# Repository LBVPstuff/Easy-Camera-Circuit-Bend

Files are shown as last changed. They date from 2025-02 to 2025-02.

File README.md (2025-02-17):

# Easy-Camera-Circuit-Bend

An easy way to circuit bend a toy camera with a CMOS chip to take glitchy pictures, with only basic skills needed in soldering.

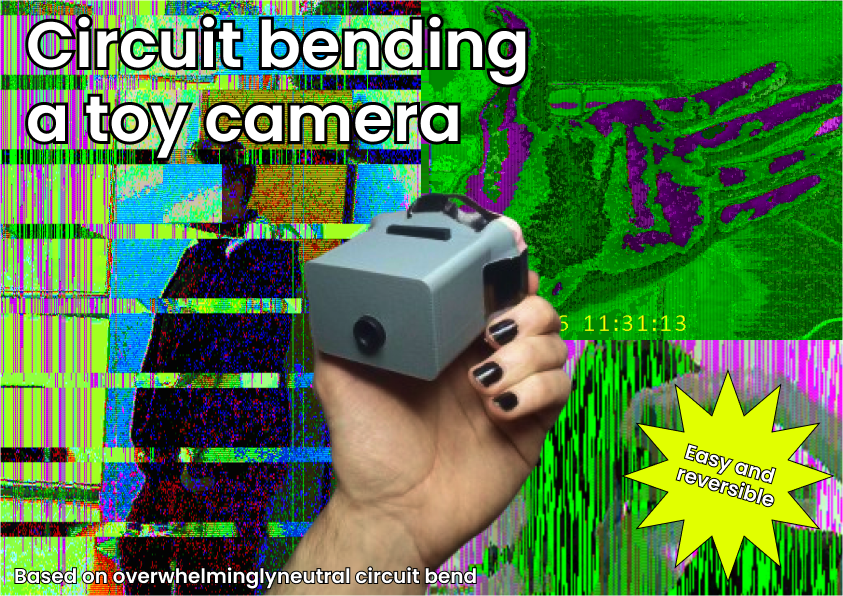
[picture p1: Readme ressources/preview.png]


:warning: **Big disclaimer here:** I did not invented this hack, I discovered it with [this cool video](https://www.youtube.com/watch?v=hnv6Nud2QAo) by [overwhelminglyneutral (cool person)](https://www.youtube.com/@oneutral101) and I wanted to add more to it while making it more practical to use, by being able to switch between different effects.

The modifications we will be doing to the camera are reversible and not directly soldered to the board, making it easy to swap if you need to get back to a normal toy camera.

## *What is circuit bending*

Wikipedia says circuit bending is the creative customization of the circuits within electronic devices such as children's toys and digital synthesizer to create new musical or visual instruments and sound generators. Circuit bending is manipulating a circuit to get an output that was not intended by the manufacturer.
It is a really interesting and creative topic, but sometimes I find that it can get quite esoteric and difficult to understand, especially if you have no knowledge in electronics to begin with. I wanted this project to be achievable by people with very little skills with soldering (like me) so everyone can try this little hack and take cool pictures. I will try my best to include a lot of details.

## *How this circuit bend works ?*

Within this camera, there is a camera module, sending information to the motherboard inside the main body. This camera basically tells what it sees throught electric signals throught 24 tiny cables and the motherboard is processing this signal to display it on the screen, save it on the SD card, add filters etc.

What we want to do is mix thoses signals together by shorting some pins together and mess with the signals being sent to the motherboard.

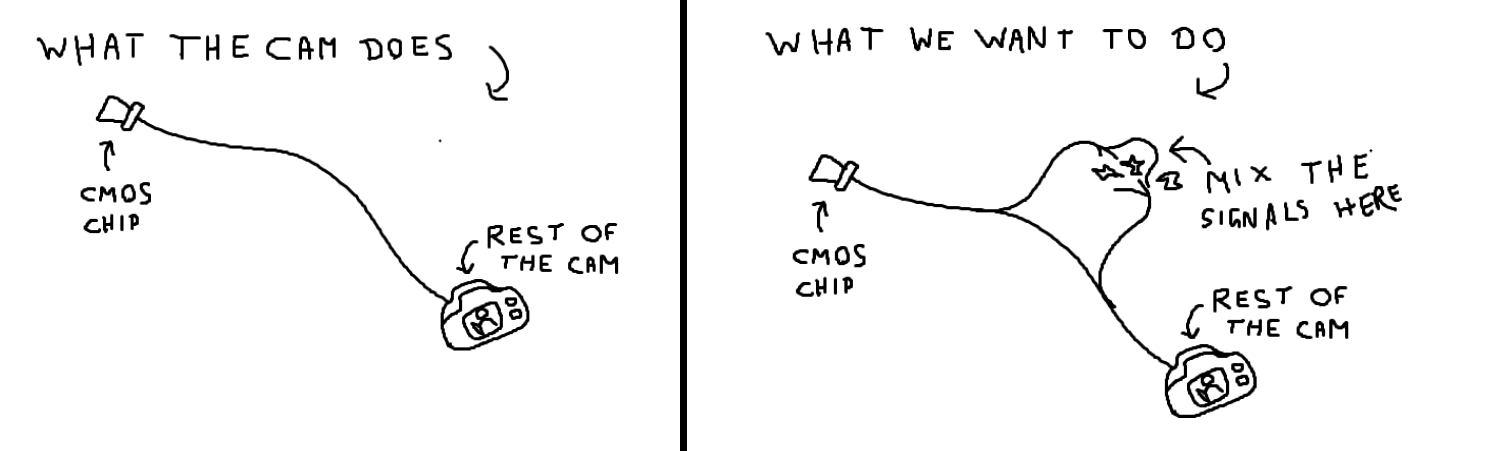
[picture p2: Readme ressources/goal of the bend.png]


To achieve this, you are supposed to solder tiny enameled copper wire to the 0.5mm ribbon cable connector pins on the main board, but it was way too difficult for me so I found an other way using adaptor cards and a spare ribbon cable. The result looks like this without a case to hold everything together :

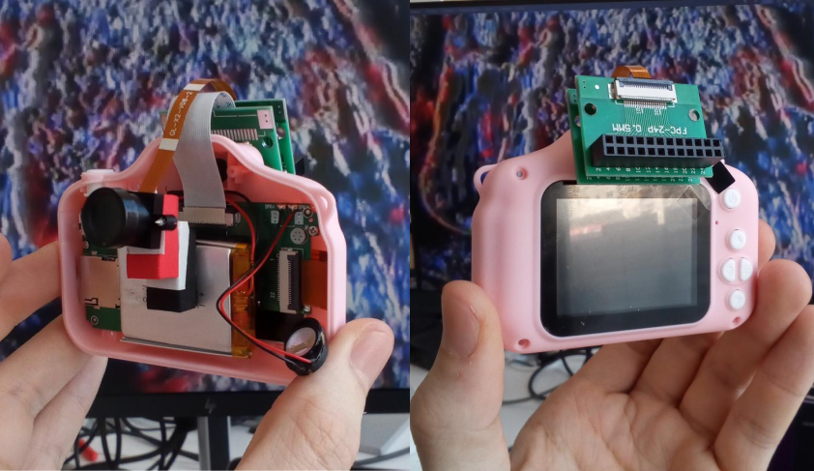
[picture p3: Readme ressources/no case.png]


## *Tools and materials you will need*

### [The toy camera](https://www.amazon.fr/Faburo-Appareil-Num%C3%A9rique-Mpixels-Gar%C3%A7ons/dp/B07W45FTG8)
The Toy camera I used was [this Faburo Toy Camera](https://www.amazon.fr/Faburo-Appareil-Num%C3%A9rique-Mpixels-Gar%C3%A7ons/dp/B07W45FTG8). It is available on amazon and is pretty cheap, around 16 euros. There are also the same cameras available on aliexpress for a little cheaper if you are willing to wait a little bit more. Also, it is a good idea to check on the seconde hand market first, I found several there.

This circuit bend probably also work on many other cheap toy camera such as theses ones:

_______________________________________________________________________________

### Two [24 pin Ribbon cable to pins converter boards](https://fr.aliexpress.com/item/1005005485116729.html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,scm-url:1007.40050.354490.0,pvid:dd1d1b7d-951f-4a07-9ccf-86fbf27bccbe,tpp_buckets:668%232846%238113%231998&pdp_npi=4%40dis%21EUR%212.00%210.99%21%21%2114.70%217.27%21%40211b61a417367906687343405e3798%2112000033269437110%21rec%21FR%21%21ABX&utparam-url=scene%3ApcDetailTopMoreOtherSeller%7Cquery_from%3A)
I ordered them from aliexpress because it was the easiest way for me to souce these parts. The most important thing to know is that we need a **24pin adaptor with 0.5mm of paths thickness**. So make sure to tick the same boxes like in the picture when you order. **We will need 2 of these.**

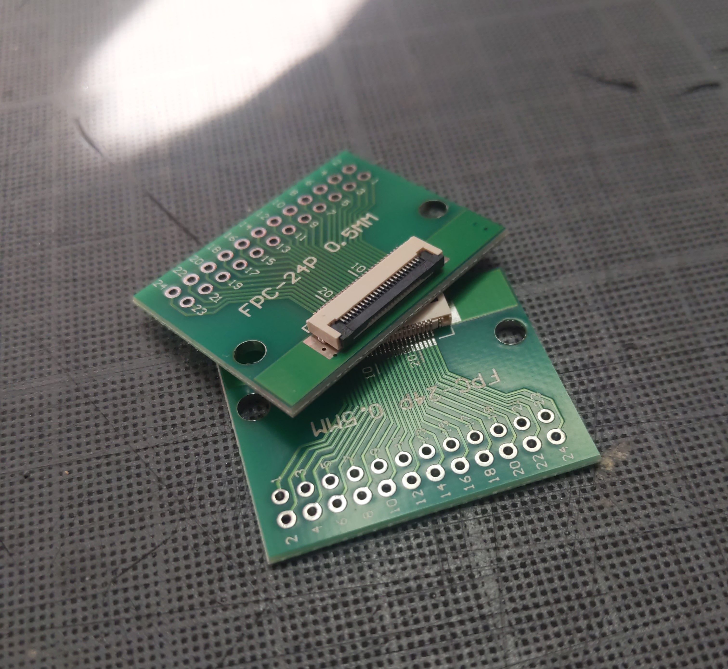
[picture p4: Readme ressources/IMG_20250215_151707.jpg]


_______________________________________________________________________________

### Two rows 24 pins headers

I used a longer one that I trimmed to size, but you can find 24pins ones if you want. This will be used to connect the two adapter boards together. Alternatively, you can connect the big pins from the adapter boards directly to other stuff you want to use to short the pins, but I find this much easier and will be handy later.

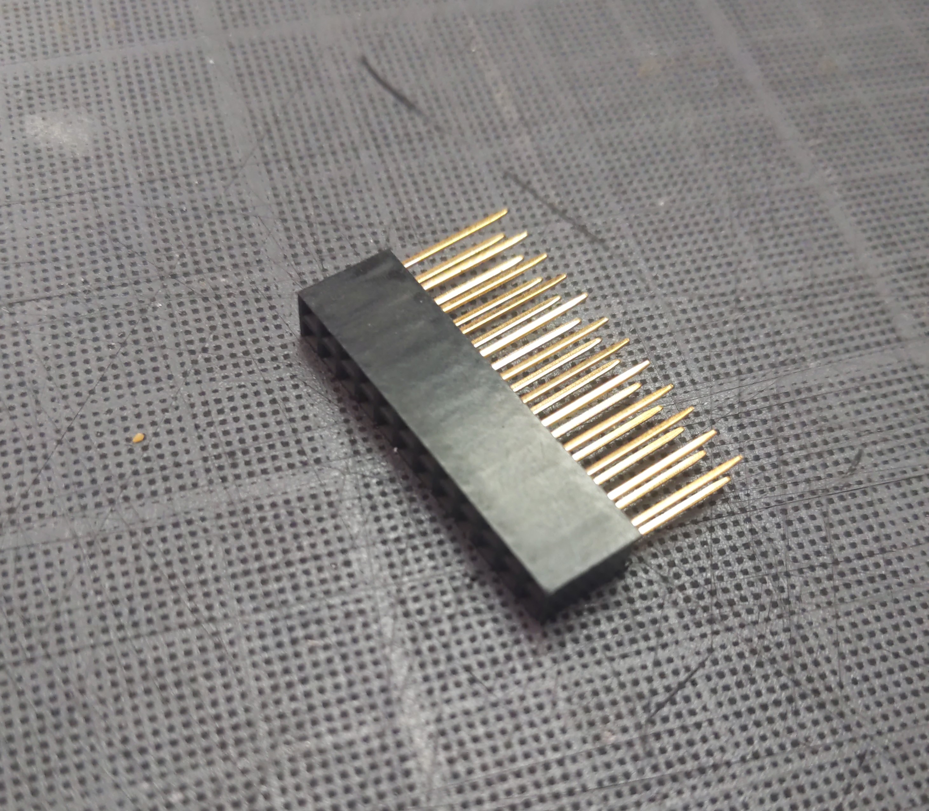
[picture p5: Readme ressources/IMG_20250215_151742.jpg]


_______________________________________________________________________________

### Longer [24pin ribbon cable](https://fr.aliexpress.com/item/1005005982573926.html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)
In order to connect the adaptor boards back to the main board of the camera, we will need another ribbon cable like this one :
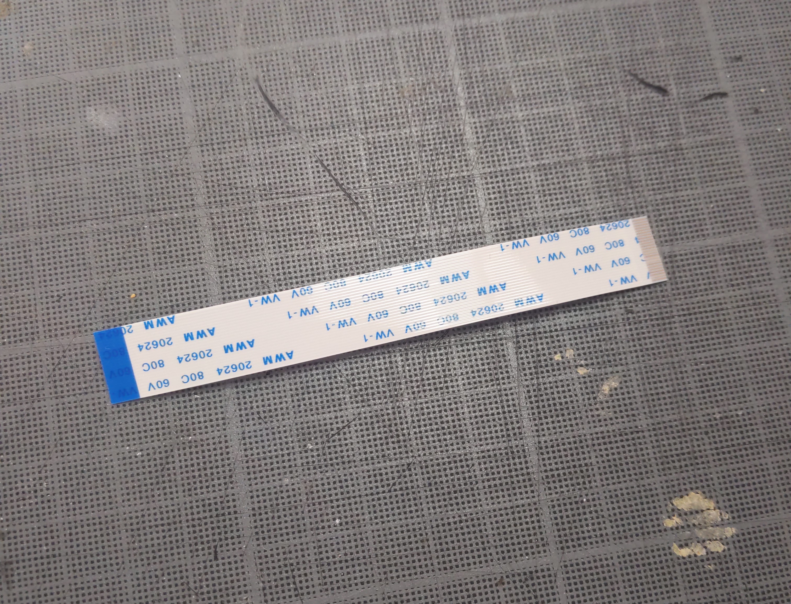
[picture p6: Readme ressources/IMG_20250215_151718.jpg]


:warning: Make sure it is a **24pin ribbon cable with a thickness of 0.5mm**. I chose a length of 10cm, since it will more than enough for my case.

_______________________________________________________________________________

### Jumper wire
Or any wire that fits into our 24 pins header just to trigger the bends once we are finished.

_______________________________________________________________________________

### A soldering Iron

Any soldering iron will do, we are not going to do complex stuff with it, just make sure its tip is clean. If you don't know of to solder, i found [this video that cover all the steps we will need](https://www.youtube.com/watch?v=Qps9woUGkvI).

_______________________________________________________________________________

### Solder
Try using lead free solder, but again any solder will do the trick here.

_______________________________________________________________________________

### A small phillips screwdriver
We will be using it to disassemble the camera

## *Step by step guide*

I made a video tutorial on Youtube that covers all the steps to assemble the module, i find it easier to understand this way:

(https://www.youtube.com/watch?v=pKovYRPuqpo)

Also you can find the complete pinout of the bends I found with [this link](https://docs.google.com/spreadsheets/d/120eRuoZbcSEhcIwTfrmM8TAaZlizbV74gkXWp9CGXoM/edit?usp=sharing), or in PDF format in the folder Pinout] of this repo. As mentionned in the video, **I strongly advise you to test out the bends on your particular camera**, since those are very cheap and vary a lot on one another, even with the same models.

After completing the module and plugging it into the camera, you will need a way to hold everything together nicely. To do so, I 3D modeled a new case for the camera, with more space to fit everything into it. If you have access to a 3D printer, you can print this with the flat side facing down with no support.

Then you just have to screw the camera module inside it, stick the connector pins throught the hole and plug the ribbon cable back into the camera. The current case holds together with duct tape but maybe later I will 3D model a new cas uses the screws used the hold the camera together originally.

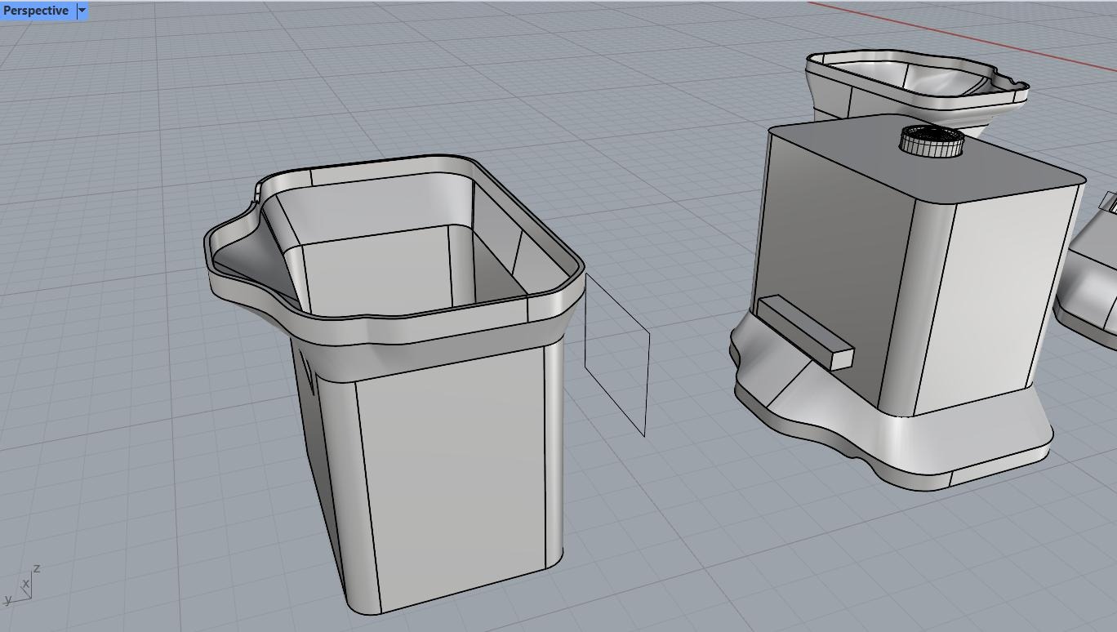
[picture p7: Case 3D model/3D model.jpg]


:warning: **Make sure to test if the module works before putting it into its new case or it will be annoying to take it appart**

The 3D model can be found in this repo into the **Case 3D model folder**.

## *Future of this project*

I plan on doing "presets" for this camera. Using the exposed connector, i can plug a specific short that creates a glitch effect I like and have multiple of those presets modules into my pocket and switch between them idk.

Also I would like to do some "shields" that plung onto the connectors and able manual control with switch and potentiometers over the more interestings bends such as the pin 1 6 and 20. I have drawn some ideas and I could be a cool project to learn about PCB making.

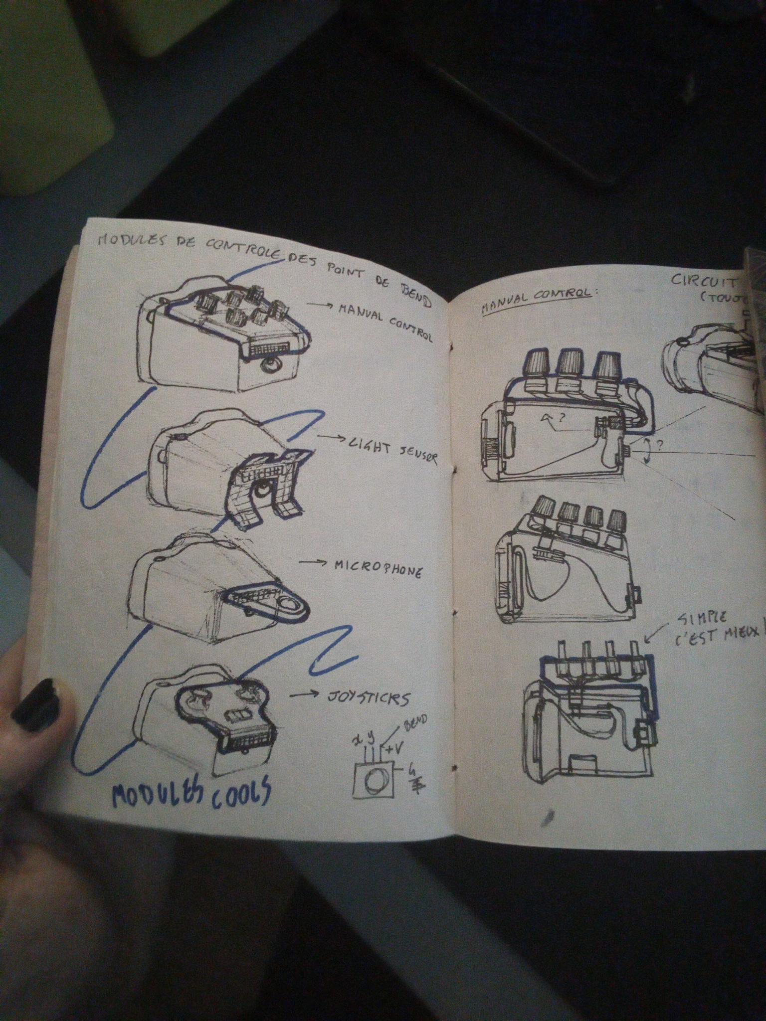
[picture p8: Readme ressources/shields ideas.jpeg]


## *Here are some picture I took with it*

The timestamp can be removed in the parameters of the camera, and the image quality (mostly the size of the image on your SD card) can be changed as well. I am using 2 jumper cables for most of my pictures.

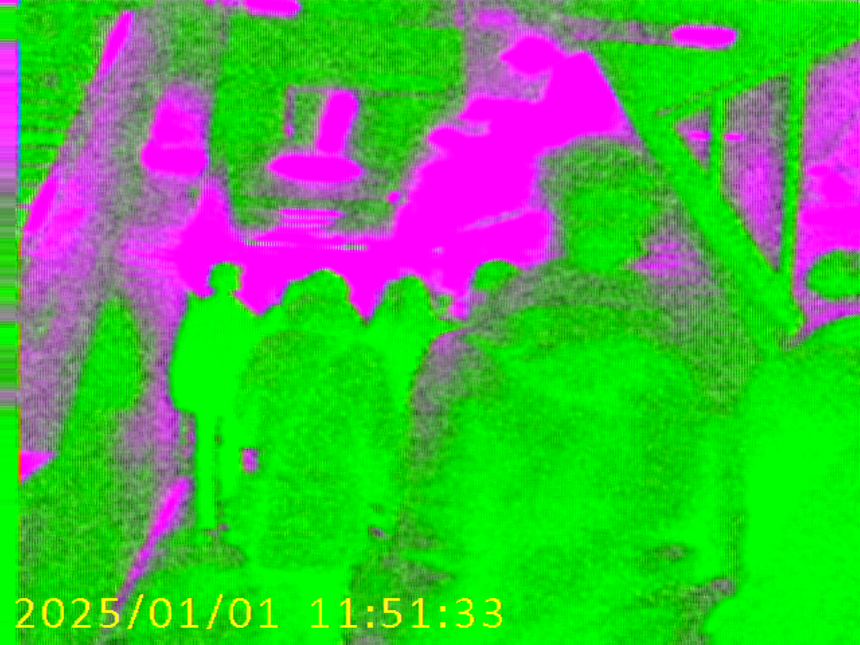
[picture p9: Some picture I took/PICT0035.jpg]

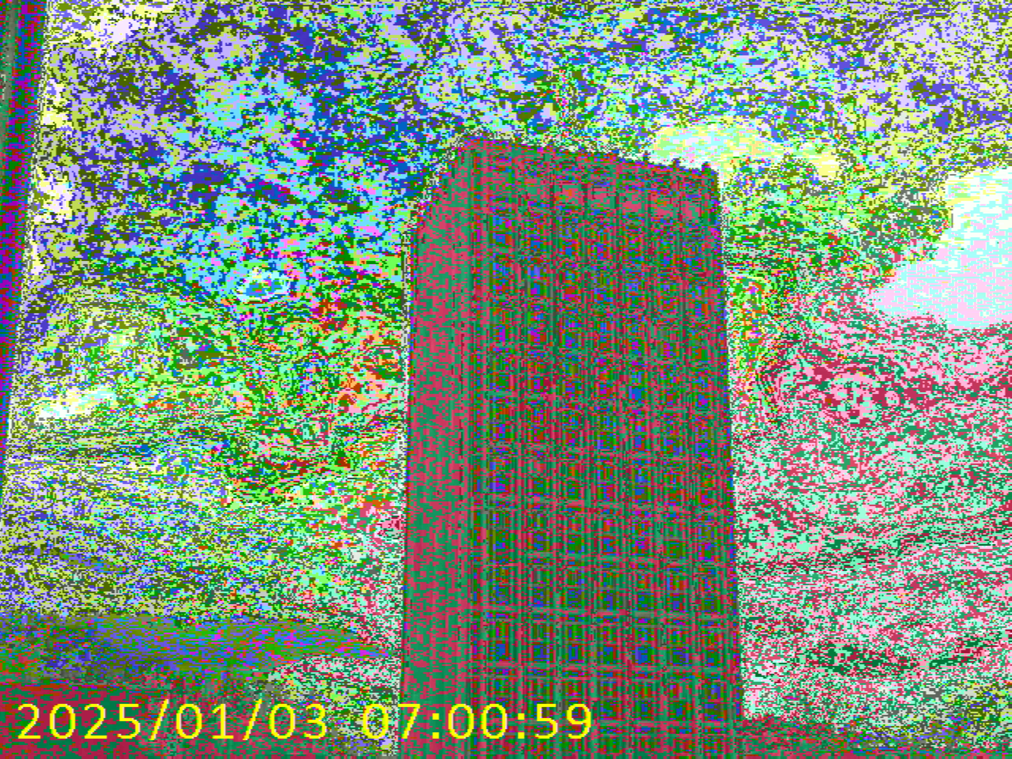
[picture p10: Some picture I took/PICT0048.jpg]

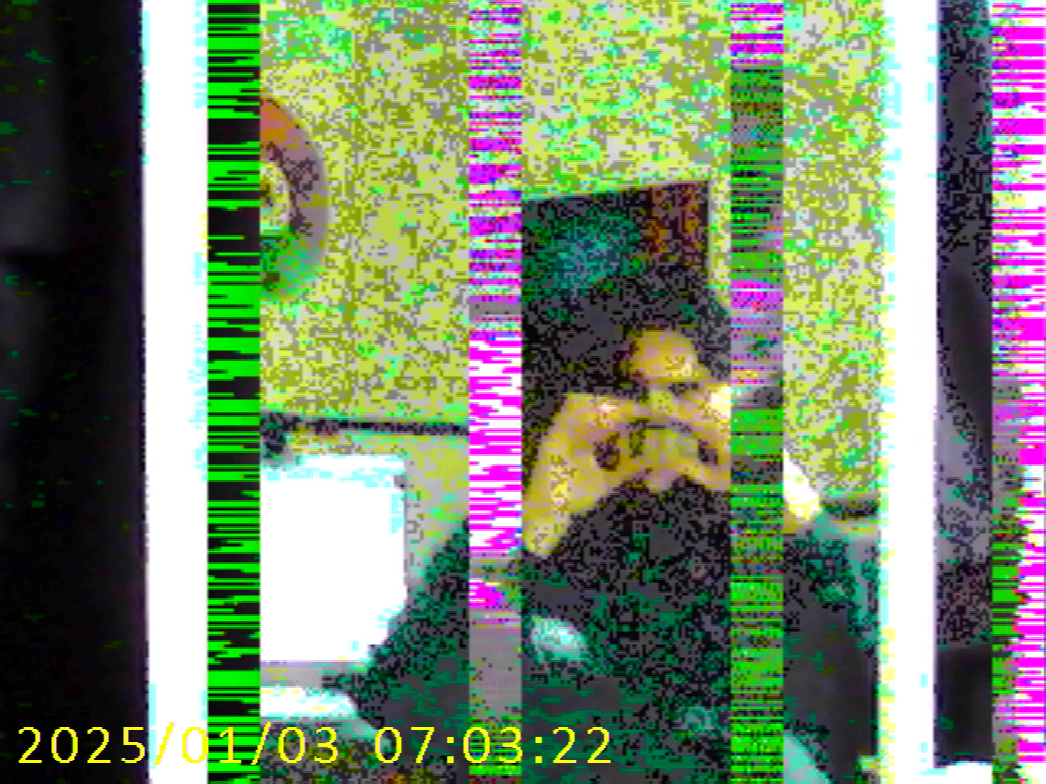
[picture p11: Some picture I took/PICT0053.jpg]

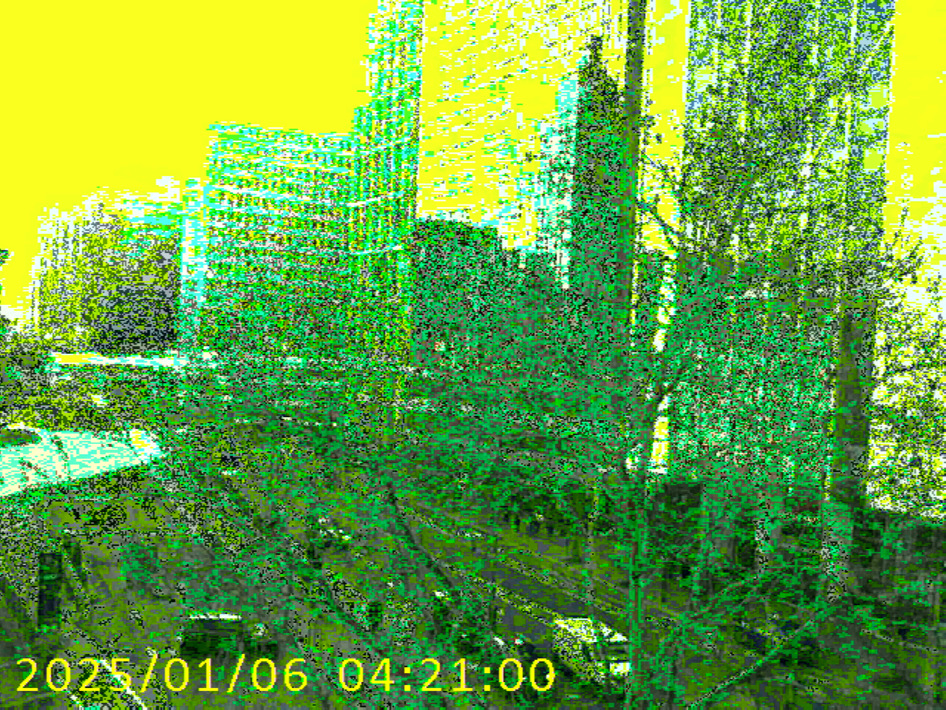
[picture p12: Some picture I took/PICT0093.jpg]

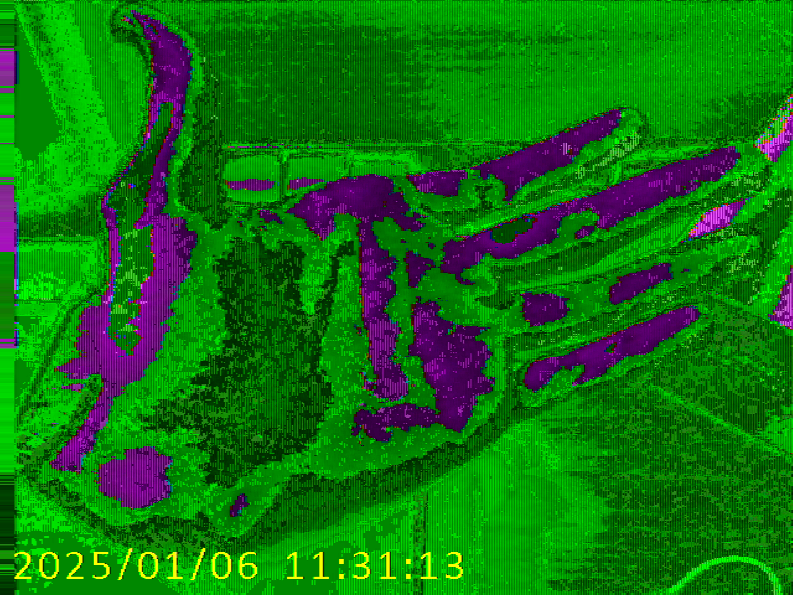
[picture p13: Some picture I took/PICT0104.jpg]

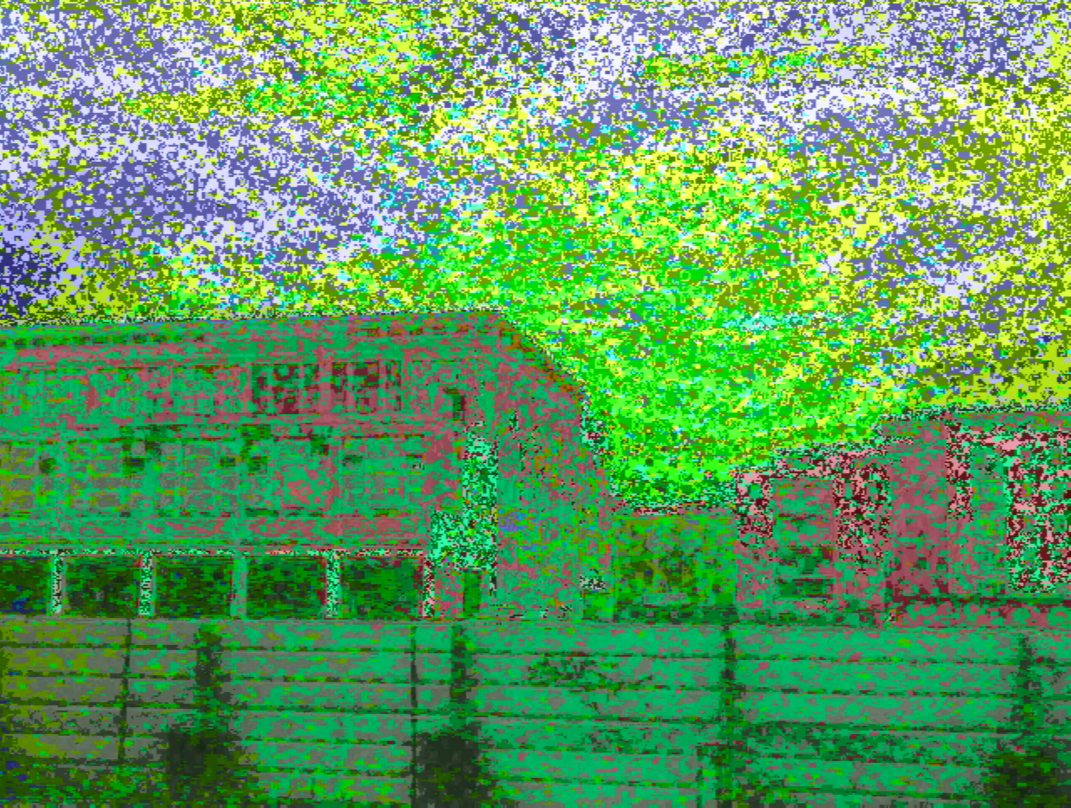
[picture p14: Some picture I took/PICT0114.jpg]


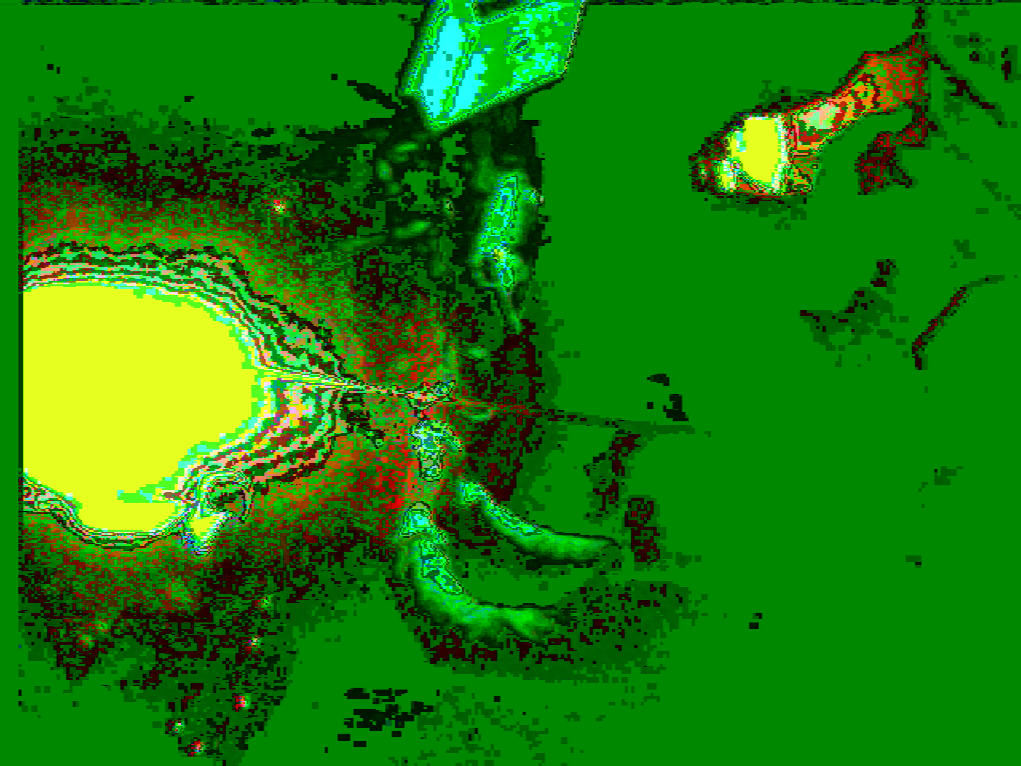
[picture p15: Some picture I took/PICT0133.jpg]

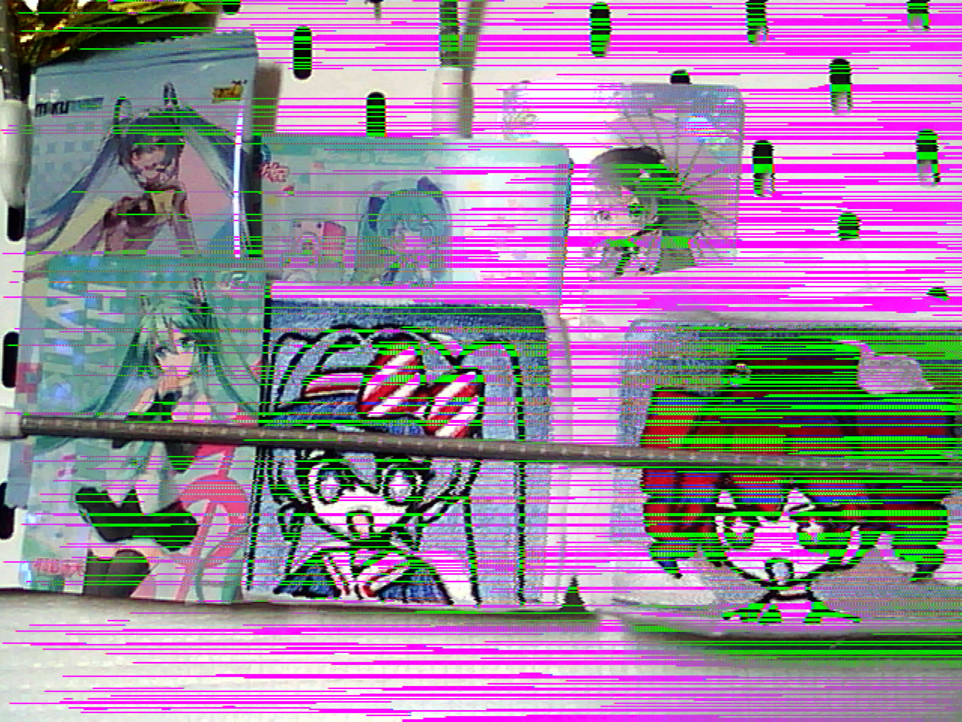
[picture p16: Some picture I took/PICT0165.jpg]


This work is licensed under CC BY-NC 4.0

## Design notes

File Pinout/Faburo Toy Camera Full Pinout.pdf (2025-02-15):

Faburo Toy Camera Full Pinout | PIN 1 pinout
First PIN | Second PIN | Result
1 | 2 | Nothing
1 | 3 | Nothing
1 | 4 | Nothing
1 | 5 | Faint blue filter
1 | 6 | Posterize with pink glitchy pixels effect
1 | 7 | Pink posterize effect
1 | 8 | Posterize with pink glitchy pixels effect
1 | 9 | Blue or pink posterize effect
1 | 10 | Nothing
1 | 11 | Nothing
1 | 12 | Nothing
1 | 13 | Nothing
1 | 14 | Freeze/CRASH
1 | 15 | "Thermal vision" effect
1 | 16 | Nothing
1 | 17 | Nothing
1 | 18 | Nothing
1 | 19 | Flash/Freeze/CRASH
1 | 20 | Green and yellow pixel glitchs, then crash
1 | 21 | "Thermal vision" effect
1 | 22 | "Thermal vision" effect
1 | 23 | Nothing
1 | 24 | Nothing

Faburo Toy Camera Full Pinout | PIN 2 pinout
First PIN | Second Pin | Result
2 | 1 | Nothing
2 | 3 | Nothing
2 | 4 | Nothing
2 | 5 | Nothing
2 | 6 | Nothing
2 | 7 | Nothing
2 | 8 | Nothing
2 | 9 | Nothing
2 | 10 | Nothing
2 | 11 | Nothing
2 | 12 | Nothing
2 | 13 | Nothing
2 | 14 | Nothing
2 | 15 | Nothing
2 | 16 | Nothing
2 | 17 | Nothing
2 | 18 | Nothing
2 | 19 | Nothing
2 | 20 | Nothing
2 | 21 | Nothing
2 | 22 | Nothing
2 | 23 | Nothing
2 | 24 | Nothing

Faburo Toy Camera Full Pinout | PIN 3 pinout
3 | 1 | Nothing
3 | 2 | Nothing
3 | 4 | Nothing
3 | 5 | Nothing
3 | 6 | Nothing
3 | 7 | Nothing
3 | 8 | Nothing
3 | 9 | Nothing
3 | 10 | Nothing
3 | 11 | Nothing
3 | 12 | Nothing
3 | 13 | Nothing
3 | 14 | Nothing
3 | 15 | Nothing
3 | 16 | Nothing
3 | 17 | Nothing
3 | 18 | Nothing
3 | 19 | Nothing
3 | 20 | Nothing
3 | 21 | Nothing
3 | 22 | Nothing
3 | 23 | Nothing
3 | 24 | Nothing

Faburo Toy Camera Full Pinout | PIN 4 pinout
4 | 1 | Nothing
4 | 2 | Nothing
4 | 3 | Nothing
4 | 5 | Nothing
4 | 6 | Radiactive green glitchy pixels effect
4 | 7 | Posterize with green pixels effect
4 | 8 | Faint posterize green pixels effect
4 | 9 | Faint green pixels
4 | 10 | Nothing
4 | 11 | Nothing
4 | 12 | Nothing
4 | 13 | Nothing
4 | 14 | Freeze/CRASH
4 | 15 | Nothing
4 | 16 | Nothing
4 | 17 | Nothing
4 | 18 | Nothing
4 | 19 | Flash with pixels then crash
4 | 20 | Glitchy lines effect
4 | 21 | Nothing
4 | 22 | Nothing
4 | 23 | Nothing
4 | 24 | Nothing

Faburo Toy Camera Full Pinout | PIN 5 pinout
5 | 1 | Fain blue filter
5 | 2 | Nothing
5 | 3 | Nothing
5 | 4 | Nothing
5 | 6 | Radiactive green glitchy pixels effect
5 | 7 | Posterize with pixels
5 | 8 | Posterize with pixels
5 | 9 | Faint posterize
5 | 10 | Nothing
5 | 11 | Nothing
5 | 12 | Nothing
5 | 13 | Nothing
5 | 14 | Freeze/CRASH
5 | 15 | Nothing
5 | 16 | Nothing
5 | 17 | Nothing
5 | 18 | Nothing
5 | 19 | Freeze/CRASH
5 | 20 | Glitchy lines effect
5 | 21 | Nothing
5 | 22 | Nothing
5 | 23 | Nothing
5 | 24 | Nothing

Faburo Toy Camera Full Pinout | PIN 6 pinout
6 | 1 | Posterize with pink glitchy pixels effect
6 | 2 | Nothing
6 | 3 | Nothing
6 | 4 | Radiactive green glitchy pixels effect
6 | 5 | Radiactive green glitchy pixels effect
6 | 7 | Glitchy green and yellow effect
6 | 8 | Radioactive green and yellow glitchy pixels effect
6 | 9 | Radioactive yellow glitchy pixels effect
6 | 10 | Green and yellow pixel texture effect
6 | 11 | Radioactive yellow glitchy pixels effect
6 | 12 | Nothing
6 | 13 | Radiactive green glitchy pixels effect
6 | 14 | Freeze/CRASH
6 | 15 | Radiactive green glitchy pixels effect
6 | 16 | Nothing
6 | 17 | Nothing
6 | 18 | Nothing
6 | 19 | Freeze/CRASH
6 | 20 | Radiactive green glitchy pixels effect
6 | 21 | Radiactive green glitchy pixels effect
6 | 22 | Radiactive green glitchy pixels effect
6 | 23 | Nothing
6 | 24 | Nothing

Faburo Toy Camera Full Pinout | PIN 7 pinout
7 | 1 | Pink posterize effect
7 | 2 | Nothing
7 | 3 | Nothing
7 | 4 | Posterize with green pixels effect
7 | 5 | Posterize with pixels
7 | 6 | Glitchy green and yellow effect
7 | 8 | Posterize effect
7 | 9 | Posterize effect
7 | 10 | Posterize with pixels
7 | 11 | Posterize effect
7 | 12 | Nothing
7 | 13 | Green pixels effect
7 | 14 | Freeze/CRASH
7 | 15 | Green and yellow pixels effect
7 | 16 | Nothing
7 | 17 | Nothing
7 | 18 | Nothing
7 | 19 | Freeze/CRASH
7 | 20 | Melting glitchy lines effect
7 | 21 | Green pixels effect
7 | 22 | Green pixels effect
7 | 23 | Nothing
7 | 24 | Nothing

Faburo Toy Camera Full Pinout | PIN 8 pinout
8 | 1 | Posterize with pink glitchy pixels effect
8 | 2 | Nothing
8 | 3 | Nothing
8 | 4 | Faint posterize green pixels effect
8 | 5 | Posterize with pixels
8 | 6 | Radioactive green and yellow glitchy pixels effect
8 | 7 | Posterize effect
8 | 9 | Posterize effect
8 | 10 | Posterize with pixels
8 | 11 | Posterize effect
8 | 12 | Nothing
8 | 13 | Green posterize
8 | 14 | Freeze/CRASH
8 | 15 | Green posterize
8 | 16 | Nothing
8 | 17 | Nothing
8 | 18 | Nothing
8 | 19 | Freeze/CRASH
8 | 20 | Melting glitchy lines effect
8 | 21 | Green posterize
8 | 22 | Green posterize
8 | 23 | Nothing
8 | 24 | Nothing

Faburo Toy Camera Full Pinout | PIN 9 pinout
9 | 1 | Blue or pink posterize effect
9 | 2 | Nothing
9 | 3 | Nothing
9 | 4 | Faint green pixels
9 | 5 | Faint posterize
9 | 6 | Radioactive yellow glitchy pixels effect
9 | 7 | Posterize effect
9 | 8 | Posterize effect
9 | 10 | Faint green pixels
9 | 11 | Posterize effect
9 | 12 | Nothing
9 | 13 | Green posterize
9 | 14 | Freeze/CRASH
9 | 15 | Green posterize
9 | 16 | Nothing
9 | 17 | Nothing
9 | 18 | Nothing
9 | 19 | Freeze/CRASH
9 | 20 | Melting glitchy lines effect
9 | 21 | Green posterize
9 | 22 | Green posterize
9 | 23 | Nothing
9 | 24 | Nothing

Faburo Toy Camera Full Pinout | PIN 10 pinout
10 | 1 | Nothing
10 | 2 | Nothing
10 | 3 | Nothing
10 | 4 | Nothing
10 | 5 | Nothing
10 | 6 | Green and yellow pixel texture effect
10 | 7 | Posterize with pixels
10 | 8 | Posterize with pixels
10 | 9 | Faint green pixels
10 | 11 | Faint green pixels
10 | 12 | Nothing
10 | 13 | Nothing
10 | 14 | Freeze/CRASH
10 | 15 | Nothing
10 | 16 | Nothing
10 | 17 | Nothing
10 | 18 | Nothing
10 | 19 | Freeze/CRASH
10 | 20 | Melting glichy lines effect
10 | 21 | Nothing
10 | 22 | Nothing
10 | 23 | Nothing
10 | 24 | Nothing

Faburo Toy Camera Full Pinout | PIN 11 pinout
11 | 1 | Nothing
11 | 2 | Nothing
11 | 3 | Nothing
11 | 4 | Nothing
11 | 5 | Nothing
11 | 6 | Radioactive yellow glitchy pixels effect
11 | 7 | Posterize effect
11 | 8 | Posterize effect
11 | 9 | Posterize effect
11 | 10 | Faint green pixels
11 | 12 | Nothing
11 | 13 | Posterize effect
11 | 14 | Freeze/CRASH
11 | 15 | Posterize effect
11 | 16 | Nothing
11 | 17 | Nothing
11 | 18 | Nothing
11 | 19 | Freeze/CRASH
11 | 20 | Melting glichy lines effect
11 | 21 | Posterize effect
11 | 22 | Posterize effect
11 | 23 | Nothing
11 | 24 | Nothing

Faburo Toy Camera Full Pinout | PIN 12 pinout
12 | 1 | Nothing
12 | 2 | Nothing
12 | 3 | Nothing
12 | 4 | Nothing
12 | 5 | Nothing
12 | 6 | Nothing
12 | 7 | Nothing
12 | 8 | Nothing
12 | 9 | Nothing
12 | 10 | Nothing
12 | 11 | Nothing
12 | 13 | Nothing
12 | 14 | Nothing
12 | 15 | Nothing
12 | 16 | Nothing
12 | 17 | Nothing
12 | 18 | Nothing
12 | 19 | Nothing
12 | 20 | Nothing
12 | 21 | Nothing
12 | 22 | Nothing
12 | 23 | Nothing
12 | 24 | Nothing

Faburo Toy Camera Full Pinout | PIN 13 pinout
13 | 1 | Nothing
13 | 2 | Nothing
13 | 3 | Nothing
13 | 4 | Nothing
13 | 5 | Nothing
13 | 6 | Radiactive green glitchy pixels effect
13 | 7 | Green pixels effect
13 | 8 | Green posterize
13 | 9 | Green posterize
13 | 10 | Nothing
13 | 11 | Nothing
13 | 12 | Nothing
13 | 14 | Freeze/CRASH
13 | 15 | Freeze/CRASH
13 | 16 | Nothing
13 | 17 | Nothing
13 | 18 | Nothing
13 | 19 | Freeze/CRASH
13 | 20 | Melting glitchy lines effect
13 | 21 | Nothing
13 | 22 | Nothing
13 | 23 | Nothing
13 | 24 | Nothing

Faburo Toy Camera Full Pinout | PIN 14 pinout
14 | 1 | Freeze/CRASH
14 | 2 | Freeze/CRASH
14 | 3 | Freeze/CRASH
14 | 4 | Freeze/CRASH
14 | 5 | Freeze/CRASH
14 | 6 | Freeze/CRASH
14 | 7 | Freeze/CRASH
14 | 8 | Freeze/CRASH
14 | 9 | Freeze/CRASH
14 | 10 | Freeze/CRASH
14 | 11 | Freeze/CRASH
14 | 12 | Freeze/CRASH
14 | 13 | Freeze/CRASH
14 | 15 | Freeze/CRASH
14 | 16 | Freeze/CRASH
14 | 17 | Freeze/CRASH
14 | 18 | Freeze/CRASH
14 | 19 | Freeze/CRASH
14 | 20 | Freeze/CRASH
14 | 21 | Freeze/CRASH
14 | 22 | Freeze/CRASH
14 | 23 | Freeze/CRASH
14 | 24 | Freeze/CRASH

Faburo Toy Camera Full Pinout | PIN 15 pinout
15 | 1 | "Thermal vision" effect
15 | 2 | Nothing
15 | 3 | Nothing
15 | 4 | Nothing
15 | 5 | Nothing
15 | 6 | Radiactive green glitchy pixels effect
15 | 7 | Green and yellow pixels effect
15 | 8 | Green posterize
15 | 9 | Green posterize
15 | 10 | Nothing
15 | 11 | Posterize effect
15 | 12 | Nothing
15 | 13 | Freeze/CRASH
15 | 14 | Freeze/CRASH
15 | 16 | Nothing
15 | 17 | Nothing
15 | 18 | Nothing
15 | 19 | Freeze/CRASH
15 | 20 | Freezes a part of the screen and glitch the rest/ venetian blinds effect
15 | 21 | Nothing
15 | 22 | Nothing
15 | 23 | Nothing
15 | 24 | Nothing

Faburo Toy Camera Full Pinout | PIN 16 pinout
16 | 1 | Nothing
16 | 2 | Nothing
16 | 3 | Nothing
16 | 4 | Nothing
16 | 5 | Nothing
16 | 6 | Nothing
16 | 7 | Nothing
16 | 8 | Nothing
16 | 9 | Nothing
16 | 10 | Nothing
16 | 11 | Nothing
16 | 12 | Nothing
16 | 13 | Nothing
16 | 14 | Nothing
16 | 15 | Nothing
16 | 17 | Nothing
16 | 18 | Nothing
16 | 19 | Nothing
16 | 20 | Nothing
16 | 21 | Nothing
16 | 22 | Nothing
16 | 23 | Nothing
16 | 24 | Nothing

Faburo Toy Camera Full Pinout | PIN 17 pinout
17 | 1 | Nothing
17 | 2 | Nothing
17 | 3 | Nothing
17 | 4 | Nothing
17 | 5 | Nothing
17 | 6 | Nothing
17 | 7 | Nothing
17 | 8 | Nothing
17 | 9 | Nothing
17 | 10 | Nothing
17 | 11 | Nothing
17 | 12 | Nothing
17 | 13 | Nothing
17 | 14 | Nothing
17 | 15 | Nothing
17 | 16 | Nothing
17 | 18 | Nothing
17 | 19 | Nothing
17 | 20 | Nothing
17 | 21 | Nothing
17 | 22 | Nothing
17 | 23 | Nothing
17 | 24 | Nothing

Faburo Toy Camera Full Pinout | PIN 18 pinout
18 | 1 | Nothing
18 | 2 | Nothing
18 | 3 | Nothing
18 | 4 | Nothing
18 | 5 | Nothing
18 | 6 | Nothing
18 | 7 | Nothing
18 | 8 | Nothing
18 | 9 | Nothing
18 | 10 | Nothing
18 | 11 | Nothing
18 | 12 | Nothing
18 | 13 | Nothing
18 | 14 | Nothing
18 | 15 | Nothing
18 | 16 | Nothing
18 | 17 | Nothing
18 | 19 | Nothing
18 | 20 | Nothing
18 | 21 | Nothing
18 | 22 | Nothing
18 | 23 | Nothing
18 | 24 | Nothing

Faburo Toy Camera Full Pinout | PIN 19 pinout
19 | 1 | Freeze/CRASH
19 | 2 | Freeze/CRASH
19 | 3 | Freeze/CRASH
19 | 4 | Freeze/CRASH
19 | 5 | Freeze/CRASH
19 | 6 | Freeze/CRASH
19 | 7 | Freeze/CRASH
19 | 8 | Freeze/CRASH
19 | 9 | Freeze/CRASH
19 | 10 | Freeze/CRASH
19 | 11 | Freeze/CRASH
19 | 12 | Freeze/CRASH
19 | 13 | Freeze/CRASH
19 | 14 | Freeze/CRASH
19 | 15 | Freeze/CRASH
19 | 16 | Freeze/CRASH
19 | 17 | Freeze/CRASH
19 | 18 | Freeze/CRASH
19 | 20 | Freeze/CRASH
19 | 21 | Freeze/CRASH
19 | 22 | Freeze/CRASH
19 | 23 | Freeze/CRASH
19 | 24 | Freeze/CRASH

Faburo Toy Camera Full Pinout | PIN 20 pinout
20 | 1 | Green and yellow pixel glitchs, then crash
20 | 2 | Nothing
20 | 3 | Nothing
20 | 4 | Glitchy lines effect
20 | 5 | Glitchy lines effect
20 | 6 | Radiactive green glitchy pixels effect
20 | 7 | Melting glitchy lines effect
20 | 8 | Melting glitchy lines effect
20 | 9 | Melting glitchy lines effect
20 | 10 | Melting glitchy lines effect
20 | 11 | Melting glitchy lines effect
20 | 12 | Nothing
20 | 13 | Melting glitchy lines effect
20 | 14 | Freeze/CRASH
20 | 15 | Freezes a part of the screen and glitch the rest/ venetian blinds effect
20 | 16 | Nothing
20 | 17 | Nothing
20 | 18 | Nothing
20 | 19 | Freeze/CRASH
20 | 21 | Freezes the screen and can create a venetian blind effect or crash
20 | 22 | Freezes the screen and can create a venetian blind effect or crash
20 | 23 | Nothing
20 | 24 | Nothing

Faburo Toy Camera Full Pinout | PIN 21 pinout
21 | 1 | "Thermal vision" effect
21 | 2 | Nothing
21 | 3 | Nothing
21 | 4 | Nothing
21 | 5 | Nothing
21 | 6 | Radiactive green glitchy pixels effect
21 | 7 | Green pixels effect
21 | 8 | Green posterize
21 | 9 | Green posterize
21 | 10 | Nothing
21 | 11 | Posterize effect
21 | 12 | Nothing
21 | 13 | Nothing
21 | 14 | Freeze/CRASH
21 | 15 | Nothing
21 | 16 | Nothing
21 | 17 | Nothing
21 | 18 | Nothing
21 | 19 | Freeze/CRASH
21 | 20 | Freezes the screen and can create a venetian blind effect or crash
21 | 22 | Nothing
21 | 23 | Nothing
21 | 24 | Nothing

Faburo Toy Camera Full Pinout | PIN 22 pinout
22 | 1 | "Thermal vision" effect
22 | 2 | Nothing
22 | 3 | Nothing
22 | 4 | Nothing
22 | 5 | Nothing
22 | 6 | Radiactive green glitchy pixels effect
22 | 7 | Green pixels effect
22 | 8 | Green posterize
22 | 9 | Green posterize
22 | 10 | Nothing
22 | 11 | Posterize effect
22 | 12 | Nothing
22 | 13 | Nothing
22 | 14 | Freeze/CRASH
22 | 15 | Nothing
22 | 16 | Nothing
22 | 17 | Nothing
22 | 18 | Nothing
22 | 19 | Freeze/CRASH
22 | 20 | Freezes the screen and can create a venetian blind effect or crash
22 | 21 | Nothing
22 | 23 | Nothing
22 | 24 | Nothing

Faburo Toy Camera Full Pinout | PIN 23 pinout
23 | 1 | Nothing
23 | 2 | Nothing
23 | 3 | Nothing
23 | 4 | Nothing
23 | 5 | Nothing
23 | 6 | Nothing
23 | 7 | Nothing
23 | 8 | Nothing
23 | 9 | Nothing
23 | 10 | Nothing
23 | 11 | Nothing
23 | 12 | Nothing
23 | 13 | Nothing
23 | 14 | Nothing
23 | 15 | Nothing
23 | 16 | Nothing
23 | 17 | Nothing
23 | 18 | Nothing
23 | 19 | Nothing
23 | 20 | Nothing
23 | 21 | Nothing
23 | 22 | Nothing
23 | 24 | Nothing

Faburo Toy Camera Full Pinout | PIN 24 pinout
24 | 1 | Nothing
24 | 2 | Nothing
24 | 3 | Nothing
24 | 4 | Nothing
24 | 5 | Nothing
24 | 6 | Nothing
24 | 7 | Nothing
24 | 8 | Nothing
24 | 9 | Nothing
24 | 10 | Nothing
24 | 11 | Nothing
24 | 12 | Nothing
24 | 13 | Nothing
24 | 14 | Nothing
24 | 15 | Nothing
24 | 16 | Nothing
24 | 17 | Nothing
24 | 18 | Nothing
24 | 19 | Nothing
24 | 20 | Nothing
24 | 21 | Nothing
24 | 22 | Nothing
24 | 23 | Nothing

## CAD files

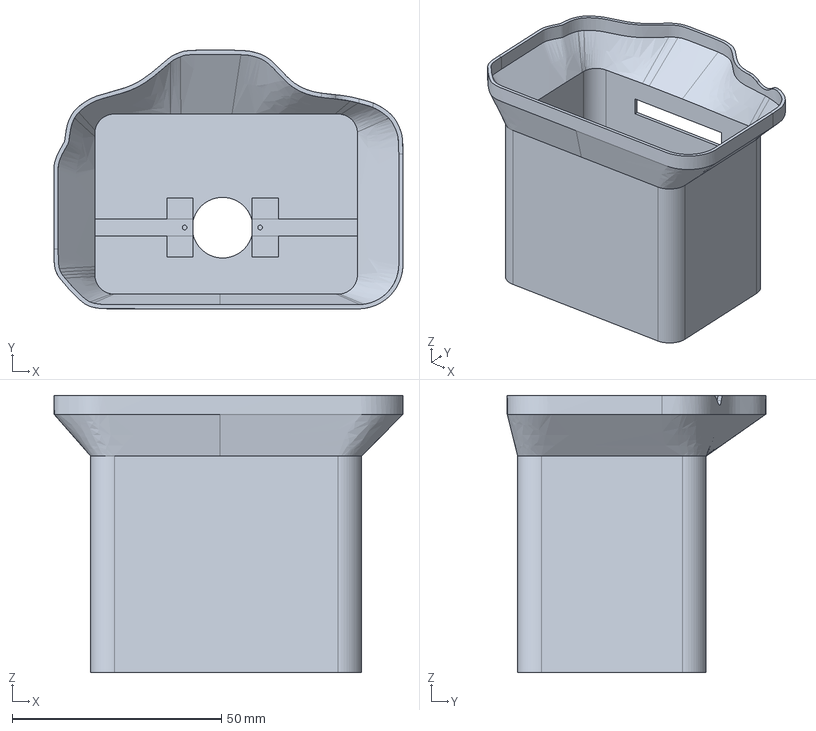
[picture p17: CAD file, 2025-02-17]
Case 3D model/case.stp
83.4 x 61.8 x 66.3 mm

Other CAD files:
Case 3D model/camera case v2.stl
Case 3D model/case.obj
